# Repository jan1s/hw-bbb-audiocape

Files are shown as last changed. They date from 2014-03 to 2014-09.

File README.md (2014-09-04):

hw-bbb-audiocape
================

First of all: This project is a clone of [CircuitCo Audio Cape][circuitco].

It is not commercial in any form, just fun for me to play around.
If you want an Audio Cape, go and get one of theirs.

## Hardware

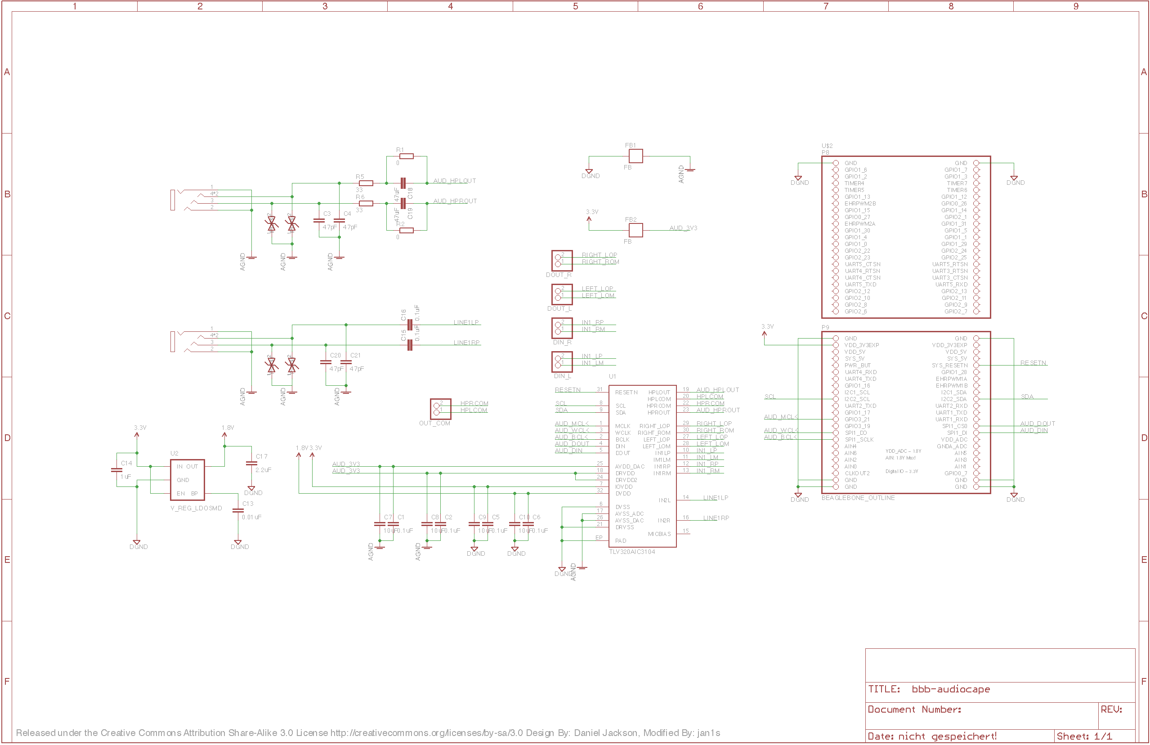
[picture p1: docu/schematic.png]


Project schematic.

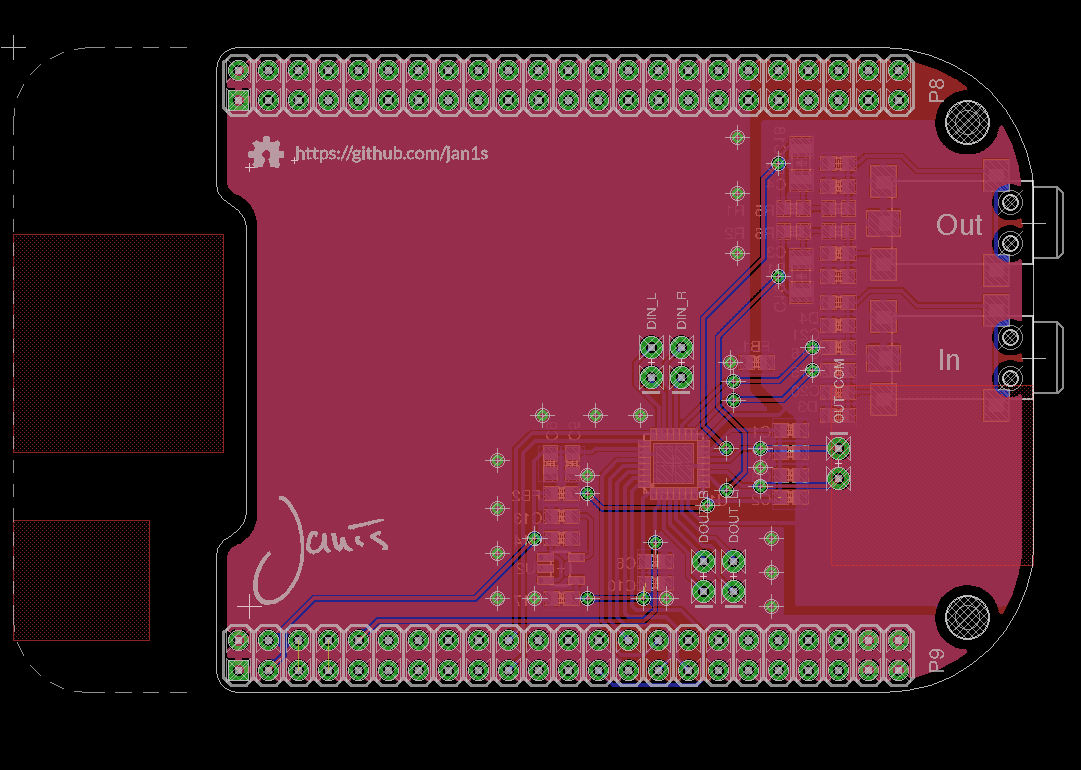
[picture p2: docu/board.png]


Render of the board.

## Setup on Arch

The setup guide is mainly taken from [eLinux.org - BBB Audio Cape RevB Getting Started][gettingstarted].

Get the tools if not already installed:

`pacman -S wget`

`pacman -S unzip`

`pacman -S dct-overlay`

Download and unzip the device tree source:

`wget http://elinux.org/images/1/10/BB-BONE-AUDI-02-00A0.zip`

`unzip BB-BONE-AUDI-02-00A0.zip`

Compile the device tree file and move it to /lib/firmware:

`dtc -O dtb -o BB-BONE-AUDI-02-00A0.dtbo -b 0 -@ BB-BONE-AUDI-02-00A0.dts`

`mv BB-BONE-AUDI-02-00A0.dtbo /lib/firmware`

Notice that the dtc-overlay version needs to be installed, since the old dtc is not accepting the @ option.

The Cape is sharing the audio signal with the onboard HDMI. Therefore HDMI audio needs to be disabled.
Edit the uEnv.txt file, that your uboot is using:

`optargs=capemgr.disable_partno=BB-BONELT-HDMI`

In order to activate the cape you need to reboot.
Load the Device Tree file for the cape:

`echo BB-BONE-AUDI-02 > /sys/devices/bone_capemgr*/slots`

To make that persistent just add the following line in /etc/default/capemgr :

`CAPE=BB-BONE-AUDI-02`

## Test and play

Play alternating noise on the 2 output channels:

`speaker-test -c 2`

Play alternating sine waves on the 2 output channels:

`speaker-test -c 2 -t sine`

## BOM
| Identifier | Type/Value | Quantity | Comment | Supplier Id | Supplier |
| --- | --- | --- | --- | --- | --- |
| R1, R2 | 0 Ω | 2 | not populated | SMD-0603 0  | [Reichelt][reichelt] |
| R5, R6 | 33 Ω | 2 |  | SMD-0603 33 | [Reichelt][reichelt] |
| C3, C4, C20, C21 | 47 pF | 2 |  | NPO-G0603 47P | [Reichelt][reichelt] |
| C13 | 10 nF | 1 |  | X7R-G0603 10N | [Reichelt][reichelt] |
| C1, C2, C5, C6, C15, C16 | 100 nF | 6 |  | X7R-G0603 100N | [Reichelt][reichelt] |
| C7-C10, C14, C17 | 10 µF | 6 |  | X5R-G0603 10/6 | [Reichelt][reichelt] |
| C18, C19 | 47 µF | 2 |  | X5R-G1206 47/6 | [Reichelt][reichelt] |
| J1, J2 | 4pol TRS Jack | 2 |  | LUM 1503-13V | [Reichelt][reichelt] |
| J3, J4 | 2row Pin Header | 2 |  | SL 2X25G 2,54 | [Reichelt][reichelt] |
| D1-D4 | Suppressor Diodes | 4 |  | 863-ESD9B3.3ST5G | [Mouser][mouser] |
| U1 | Stereo CODEC | 1 |  | 595-TLV320C3104IRHBT | [Mouser][mouser] |
| U2 | LDO 1.8V | 1 |  | 595-TLV70218DBVR | [Mouser][mouser] |

[reichelt]: http://www.reichelt.de
[mouser]: http://mouser.com

[itead-pcb]: http://imall.iteadstudio.com/open-pcb/pcb-prototyping.html

[circuitco]: http://elinux.org/CircuitCo:Audio_Cape_RevB
[gettingstarted]: http://elinux.org/BBB_Audio_Cape_RevB_Getting_Started

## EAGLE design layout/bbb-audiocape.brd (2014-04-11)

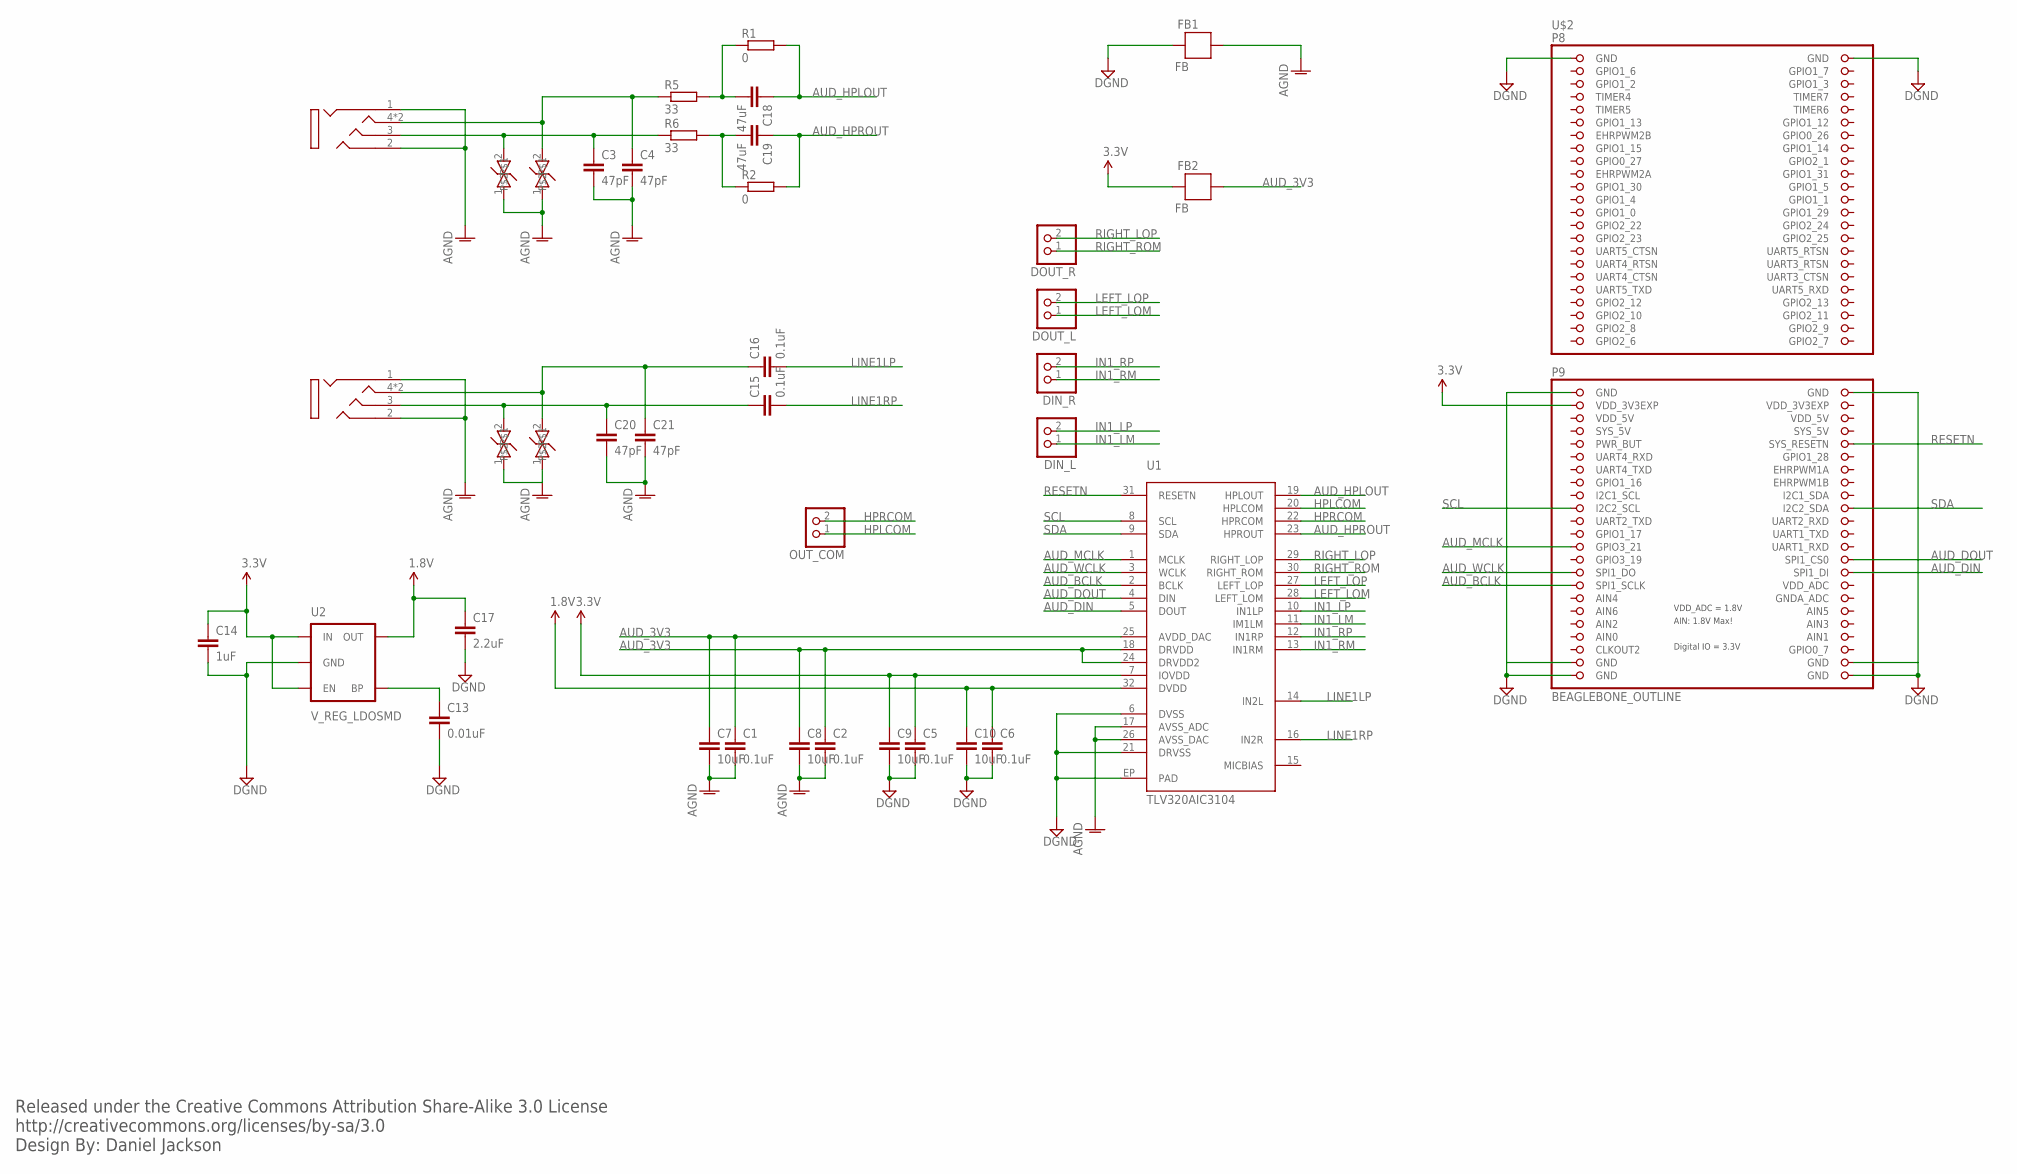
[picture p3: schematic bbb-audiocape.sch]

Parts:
C1, C2, C5, C6, C15, C16: 0.1uF; C0603
C3, C4, C20, C21: 47pF; C0603
C7, C8, C9, C10: 10uF; C0603
C13: 0.01uF; C0603
C14: 1uF; C0603
C17: 2.2uF; C0603
C18, C19: 47uF; C1206
D1, D2, D3, D4: PGB0010603MR; 0603
DIN_L: HEADER-1X2ROUND; 1X02_ROUND
DIN_R: HEADER-1X2ROUND; 1X02_ROUND
DOUT_L: HEADER-1X2ROUND; 1X02_ROUND
DOUT_R: HEADER-1X2ROUND; 1X02_ROUND
FB1, FB2: FB; 0603
OUT_COM: HEADER-1X2ROUND; 1X02_ROUND
R1, R2: 0; R0603
R5, R6: 33; R0603
U1: TLV320AIC3104; QFN-32
U2: V_REG_LDOSMD; SOT23-5
U$2: BEAGLEBONE_OUTLINE; BEAGLEBONE_SHIELD
U$3, U$5: 1503_13; 1503-03

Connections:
1.8V: C6.1, C10.1, C17.1, U1.32 (DVDD), U2.5 (OUT)
3.3V: C5.1, C9.1, C14.1, FB2.2, U1.7 (IOVDD), U2.1 (IN), U2.3 (EN), U$2.49 (VDD_3V3EXP)
AGND: C1.2, C2.2, C3.2, C4.2, C7.2, C8.2, C20.2, C21.2, D1.1, D2.1, D3.1, D4.1, FB1.1, U1.17 (AVSS_ADC), U1.26 (AVSS_DAC), U$3.1, U$3.2, U$5.1, U$5.2
AUD_3V3: C1.1, C2.1, C7.1, C8.1, FB2.1, U1.18 (DRVDD), U1.24 (DRVDD2), U1.25 (AVDD_DAC)
AUD_BCLK: U1.2 (BCLK), U$2.77 (SPI1_SCLK)
AUD_DIN: U1.5 (DOUT), U$2.76 (SPI1_DI)
AUD_DOUT: U1.4 (DIN), U$2.74 (SPI1_CS0)
AUD_HPLOUT: C18.1, R1.2, U1.19 (HPLOUT)
AUD_HPROUT: C19.1, R2.2, U1.23 (HPROUT)
AUD_MCLK: U1.1 (MCLK), U$2.71 (GPIO3_21)
AUD_WCLK: U1.3 (WCLK), U$2.75 (SPI1_DO)
DGND: C5.2, C6.2, C9.2, C10.2, C13.2, C14.2, C17.2, FB1.2, U1.6 (DVSS), U1.21 (DRVSS), U1.EP (PAD), U2.2 (GND), U$2.1 (GND), U$2.2 (GND), U$2.47 (GND), U$2.48 (GND), U$2.89 (GND), U$2.90 (GND), U$2.91 (GND), U$2.92 (GND)
GNDA_ADC: U$2.80 (GNDA_ADC)
HPLCOM: OUT_COM.1, U1.20 (HPLCOM)
HPRCOM: OUT_COM.2, U1.22 (HPRCOM)
IN1_LM: DIN_L.1, U1.11 (IM1LM)
IN1_LP: DIN_L.2, U1.10 (IN1LP)
IN1_RM: DIN_R.1, U1.13 (IN1RM)
IN1_RP: DIN_R.2, U1.12 (IN1RP)
J1: C4.1, D2.2, R5.1, U$3.4, U$3.4-2 (4)
LEFT_LOM: DOUT_L.1, U1.28 (LEFT_LOM)
LEFT_LOP: DOUT_L.2, U1.27 (LEFT_LOP)
LINE1LP: C16.2, U1.14 (IN2L)
LINE1RP: C15.2, U1.16 (IN2R)
unnamed: C15.1, C20.1, D3.2, U$5.3
unnamed: C18.2, R1.1, R5.2
unnamed: C19.2, R2.1, R6.2
unnamed: C3.1, D1.2, R6.1, U$3.3
unnamed: C16.1, C21.1, D4.2, U$5.4, U$5.4-2 (4)
unnamed: C13.1, U2.4 (BP)
RESETN: U1.31 (RESETN), U$2.56 (SYS_RESETN)
RIGHT_LOP: DOUT_R.2, U1.29 (RIGHT_LOP)
RIGHT_ROM: DOUT_R.1, U1.30 (RIGHT_ROM)
SCL: U1.8 (SCL), U$2.65 (I2C2_SCL)
SDA: U1.9 (SDA), U$2.66 (I2C2_SDA)
SYS_5V: U$2.53 (SYS_5V), U$2.54 (SYS_5V)
VDD_3V3EXP: U$2.50 (VDD_3V3EXP)
VDD_5V: U$2.51 (VDD_5V), U$2.52 (VDD_5V)
VDD_ADC: U$2.78 (VDD_ADC)

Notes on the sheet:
Released under the Creative Commons Attribution Share-Alike 3.0 License http://creativecommons.org/licenses/by-sa/3.0 Design By: Daniel Jackson

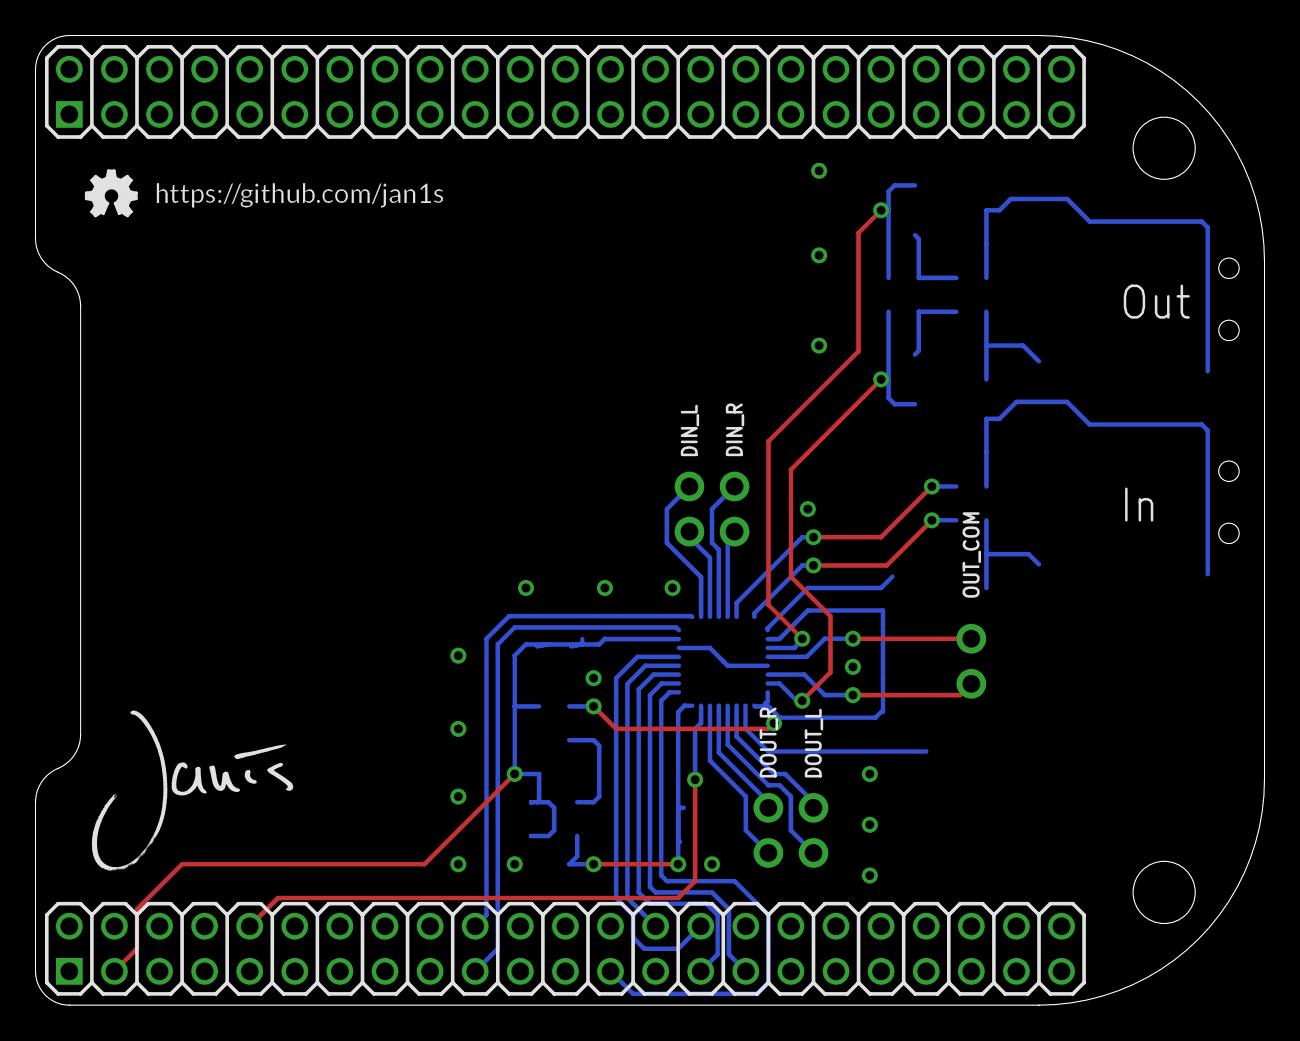
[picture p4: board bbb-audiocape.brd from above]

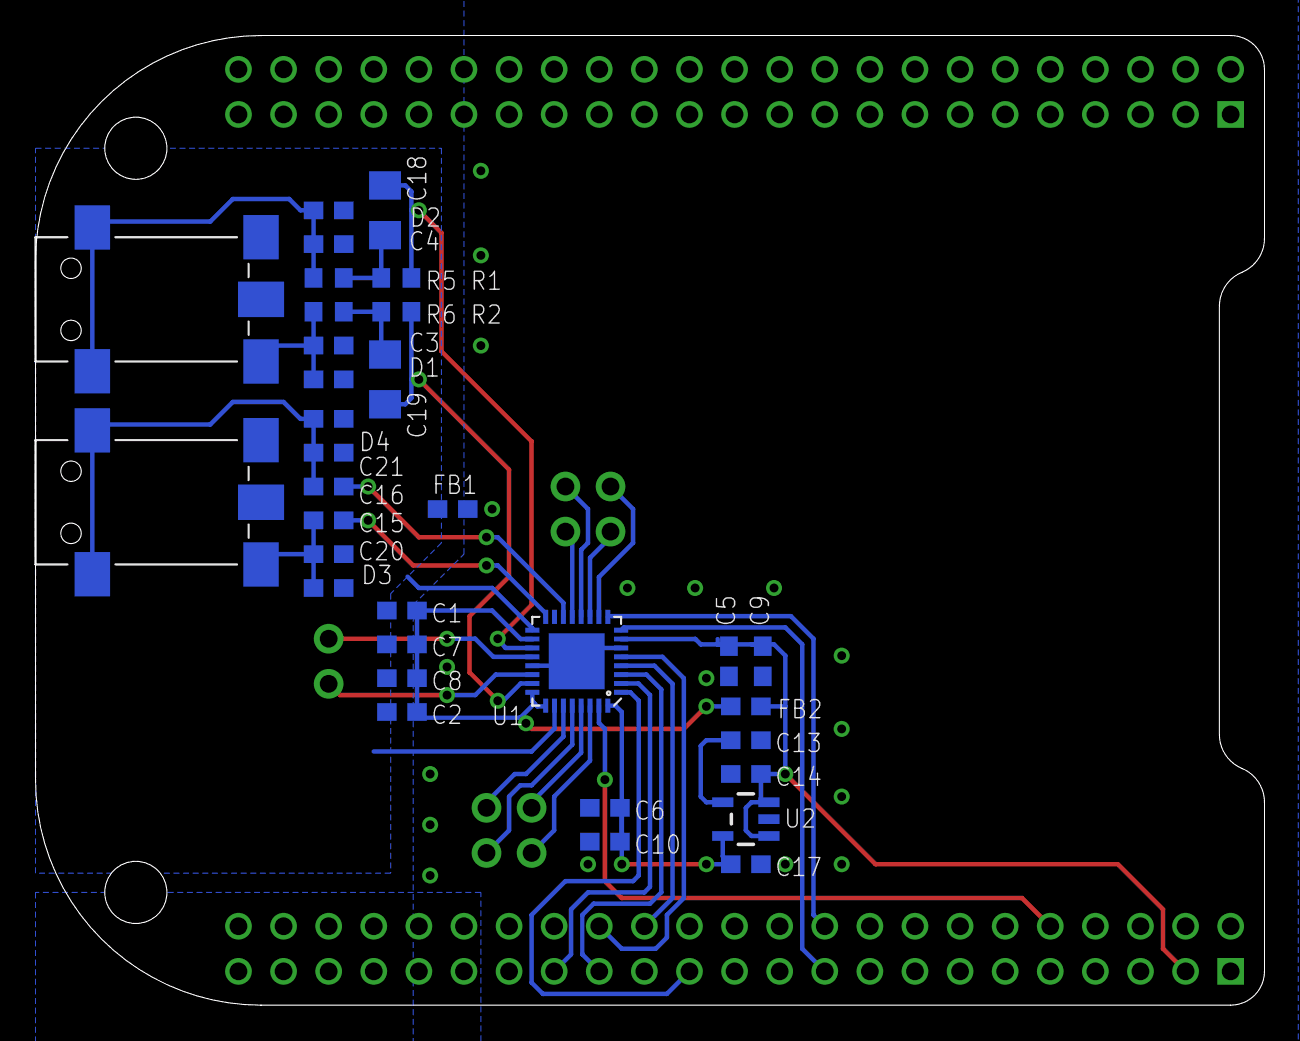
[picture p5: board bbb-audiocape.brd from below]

Board: 2 copper layers, 69.2 x 54.6 mm, 42 parts (33 on the bottom side), 36 nets.

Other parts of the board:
U$1: GITHUB/JAN1S
U$4: JANIS_10MM
U$6: OSHW_FILLX100_NOTEXT

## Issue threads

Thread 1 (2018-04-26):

Debian Stretch changes

AndyW999, 2018-04-26:
Hi

Debian has changed a lot since you did this board!

I have made a board and am having difficulty getting it to work as /sys/devices/bone_capemgr*/slots does not exist anymore.

Please could you give me some ideas to get it to work?

I know from https://elinux.org/Beagleboard:BeagleBoneBlack_Debian#U-Boot_Overlays that the hdmi audio can be disabled with disable_uboot_overlay_audio=1 but I don't know how to get the BB-BONE-AUDI-02 to be accepted.

Thanks

Andy.

PS JLCPCB made 5 PCB's in a week for $2 plus shipping!

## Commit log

2014-03-18 Finished Silkscreen
    [Audio_Cape_B1.brd]
2014-04-11 Added some vias
    [bbb-audiocape.brd, bbb-audiocape.sch]
2014-04-11 Updated BOM
2014-04-11 Completed BOM
2014-04-11 Finished production files
    [bbb-audiocape.GBL, bbb-audiocape.GBO, bbb-audiocape.GBP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]
2014-09-04 Added docu pic, Added License stuff
    [bbb-audiocape.sch]

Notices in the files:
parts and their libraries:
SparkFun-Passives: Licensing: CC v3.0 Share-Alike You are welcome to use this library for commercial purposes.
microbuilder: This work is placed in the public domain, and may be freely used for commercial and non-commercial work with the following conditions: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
